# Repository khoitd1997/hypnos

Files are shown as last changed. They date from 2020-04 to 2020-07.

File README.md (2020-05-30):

# hypnos

Module embedded inside users' laptop to "remind" them to take break and sleep

## Background

I used to have a script that runs every couple hours to turn the computer off to remind me to take a break. However, that script can be easily bypassed and it's not cross-platform. Embedding `hypnos` into the motherboard of my laptop and enabling tamperproof protection in the BIOS for the case make it much harder to bypass.

## Features

- Interact with device through phone app
  - Allow users' actions to be asynchronous, save and transmit their actions when the device is connected
  - Allow a limited number of exceptions through tokens per month: Allow users to select a time range that they don't want to be disturbed, the number of tokens needed are automatically calculated and applied
    - Waving sleep time as well as applying many tokens in the same day should cost more to prevent binge
  - Customizable work and break duration(there has to be an upper and lower limit though)
  - Limit amount of total screen time per day
  - Statistics for tracking progress
  - Foreground task to show device status as well as current phase
  - Synchronize with app to keep correct time, remind users to connect to device if they haven't for a long time
  - Indicate the current time stretch
  - Bed time and wake time
  - Battery indicator
- Flexibly adapt to user' start of day
- Hard to abuse or bypass but also possible to remove when truly necessary
- Low power consumption
- User has pending actions like changing rest interval
- Need corrective actions such as clock syncing
- Reset switch for resetting all settings(including BLE bonding information)
- Small size: About 1.5 x 1.5 inch

## Custom GATT

The custom service is called the `Timetable Service`. `Base and other UUIDs` are taken [here](https://github.com/NordicPlayground/nRF5x-custom-ble-service-tutorial):

```c
// base is f364adc9-b000-4042-ba50-05ca45bf8abc
#define UUID_SERVICE 0x1400
```

To store an hour:minute info, needs 11 bits(5 for hour, 6(least significant) for minute) for 24-hour format. All timing is stored that way except for the current time service.

All times are in GMT.

All would require authentication to read/write

| UUID | Type | Data Type | Range |
| --- | --- | --- | --- |
| 0x1401 | MORNING_CURFEW_END | time type | 24-hour format |
| 0x1402 | NIGHT_CURFEW_START | time type | 24-hour format |
| 0x1403 | WORK_DURATION_MINUTE  | uint8 | 30-120 |
| 0x1404 | BREAK_DURATION_MINUTE | uint8 | 5-15 |
| 0x1405 | ACTIVE_EXCEPTIONS | list of pair unix time | 0-4 exceptions |
| 0x1406 | TOKENS_LEFT | uint8 | depend on policy implementation |
| 0x1407 | CURRENT_UNIX_TIME | uint32 | until saturation |

Max of 4 exceptions can be active at one time

## References

[BLE Chips Power Consumption](https://www.argenox.com/library/bluetooth-low-energy/bluetooth-le-chipset-guide-2019/#ble-device-comparison)
[Picking Advertising Interval](https://www.beaconzone.co.uk/ibeaconadvertisinginterval)

[Current Time Service](https://stackoverflow.com/questions/35695711/how-to-correctly-set-the-date-and-time-in-a-bluetooth-low-energy-peripheral)

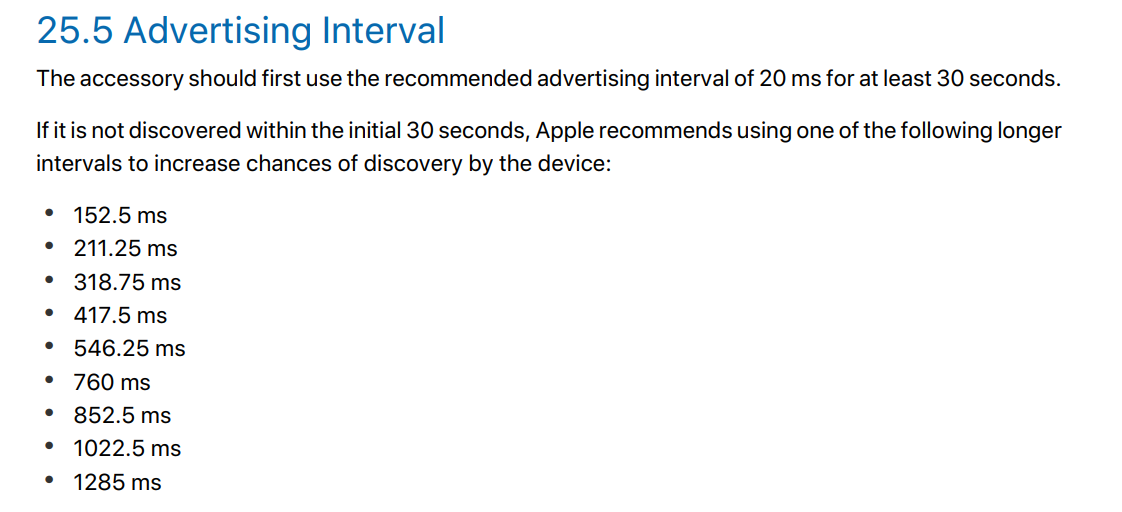
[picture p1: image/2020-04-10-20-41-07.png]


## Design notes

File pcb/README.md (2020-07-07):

# PCB

## Constraints

Use the area of the spare network card. That area has nice cable management path from the side that has the off switch.

- Max Length: 32 mm inside flat area, 8 mm outside at the first 11 mm in width (not overlapping a lot of PCB just wires)
- Max Width: 30 mm inside flat area, 20 mm overlapping with MB PCB (Need 9.5 mm for BT840F)
- Max Height: 5 mm

[NRF52 Max Voltage for GPIO][1]

The antenna inside the T480s should be 50 ohm.

## BT840F PCB Layout Notes

2-sided PCB is sufficient.

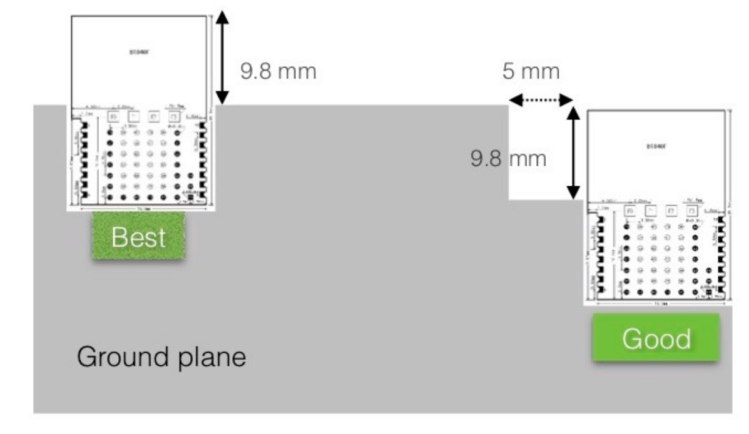
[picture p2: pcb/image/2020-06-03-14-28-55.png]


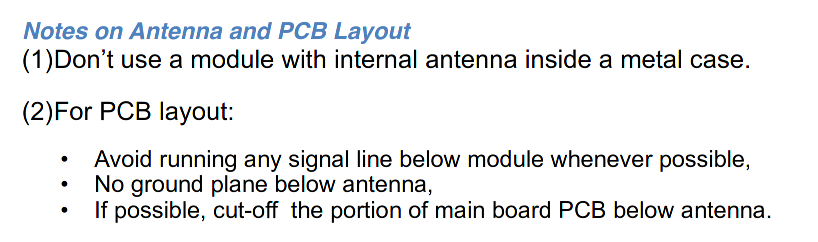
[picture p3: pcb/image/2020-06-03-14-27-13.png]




## Notes

The bare right angle pin has height 2.5 mm

[1]: https://infocenter.nordicsemi.com/index.jsp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

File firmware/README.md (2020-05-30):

# Hypnos Firmware

## Dependencies

Make sure `nRF Command Line Tools`, `JLink Driver` and `nrfutil`(pip) are installed

## How to build the firmware

The project uses `CMake` as the build system. But first, you need to generate cmake files for the nrf52 sdk since they originally supported only makefiles, then you can build various targets that do things from building the firmware to flashing the board.

```shell
# assuming working directory is the project root

# generate cmake files for sdk
# shouldn't needed to be run too often
# there will be some warnings but that's okay
./generate_cmake_file_for_sdk.sh

mkdir -p build
cd build
rm -rf ./* # if previous build was for the tests, reset the state

cmake .. -DCMAKE_TOOLCHAIN_FILE=../nrf_sdk/toolchain.cmake
cmake --build . --target flash_pca10056 # build and flash pca10056 firmware
```

A faster way than using the commandline cmake is to use the vscode CMake extension, the project already contains a file describing the cmake `nrf52 kit` to be used for building, so select that kit during configuration and you should be good.

## How to build the tests

The project uses `doctest` as its unit test framework to test files that are not hardware-depdendent. The test cases themselves are included in the source files of the code being tested themselves. To build:

```shell
# assuming working directory is the project root

mkdir -p build
cd build
rm -rf ./* # if previous build was for the firmware, reset the state

cmake ..
cmake --build . # build and run all tests by default
```

## Power Consumption Data

NRF52840 power consumption data, measured using a trueRMS multimeter with supply voltage of 3V, assuming bonded device. At the longest adv interval, the device is still detected and connected pretty fast, although to the time connect is inconsistent.

| Type | Adv Interval(0.625 ms) | uA  |
| ---- | --- | --- |
| Slow | 50 | 250 |
| Slow | 1000 | 70  |
| Slow | 3000 | 50  |
| Slow | 10000 | 40  |

## State Machine

### Top Level

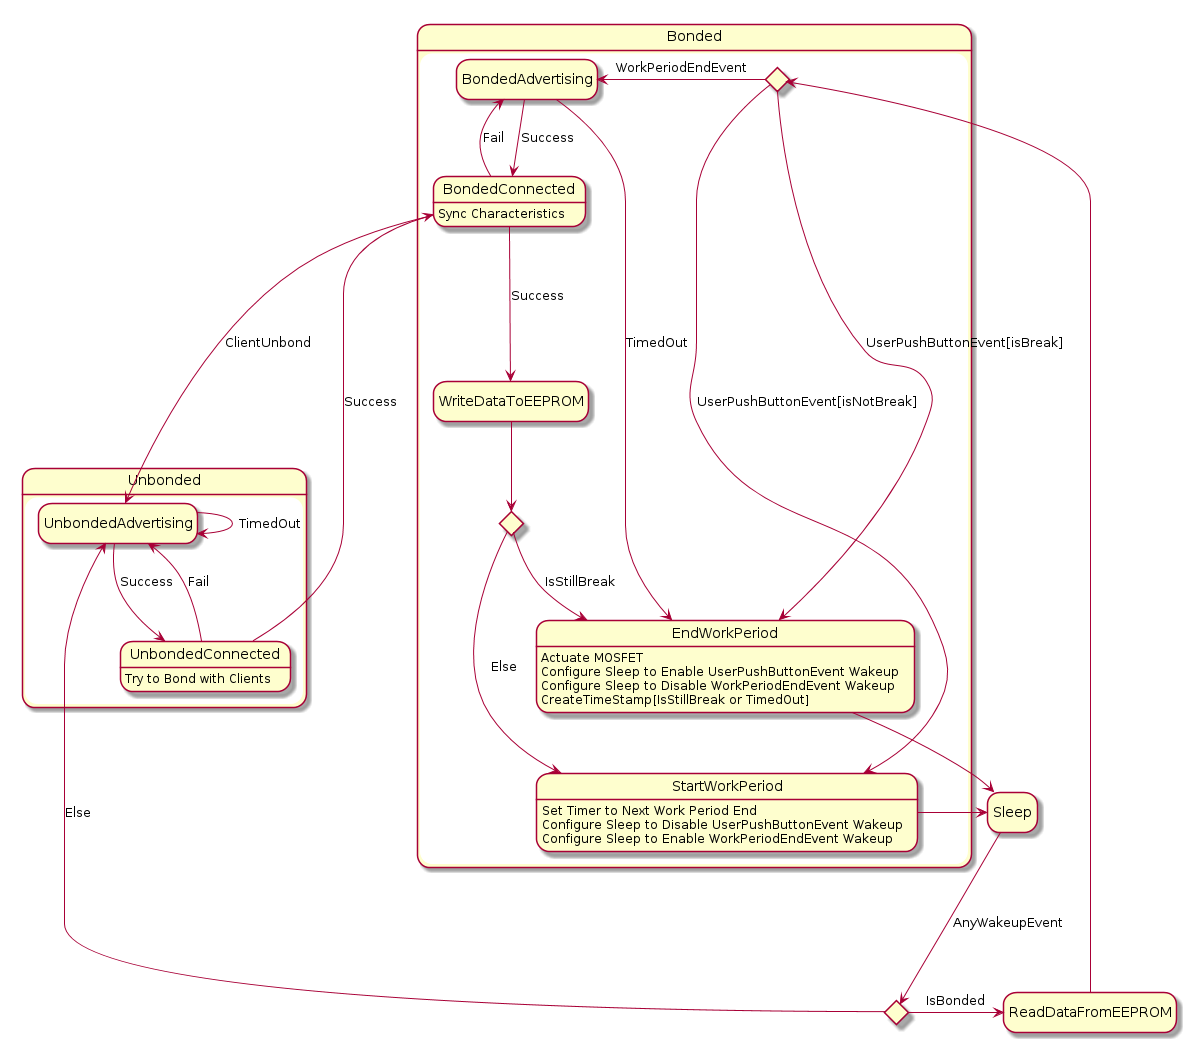
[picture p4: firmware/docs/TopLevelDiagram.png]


## References

The special event like BSP_EVENT_SYSOFF is assigned using:

```c
bsp_event_to_button_action_assign(BTN_ID_SLEEP,
                                  BSP_BUTTON_ACTION_LONG_PUSH,
                                  BSP_EVENT_SYSOFF);
```

[BSP Indication](https://infocenter.nordicsemi.com/index.jsp?topic=%2Fcom.nordic.infocenter.sdk5.v15.0.0%2Fgroup__bsp.html)
[BLE Security](https://duo.com/decipher/understanding-bluetooth-security)

[DCDC vs LDO power converter](https://devzone.nordicsemi.com/f/nordic-q-a/8106/internal-dcdc-vs-ldo-for-nrf52-series)

[Sending array in BLE data](https://devzone.nordicsemi.com/f/nordic-q-a/18040/ways-of-sending-a-float-array-as-a-value-of-a-characteristic)

[Software RTC](https://github.com/NordicPlayground/nrf5-calendar-example)
[Directed Advertising](https://devzone.nordicsemi.com/f/nordic-q-a/39950/directed-advertising---how-to-make-it-work)
[Power Optimization](https://www.argenox.com/library/bluetooth-low-energy/ble-advertising-primer/)
[CR2032 and NRF52](https://devzone.nordicsemi.com/f/nordic-q-a/36982/cr2032-coin-cell-battery-life-estimation-with-nrf52-as-beacon)

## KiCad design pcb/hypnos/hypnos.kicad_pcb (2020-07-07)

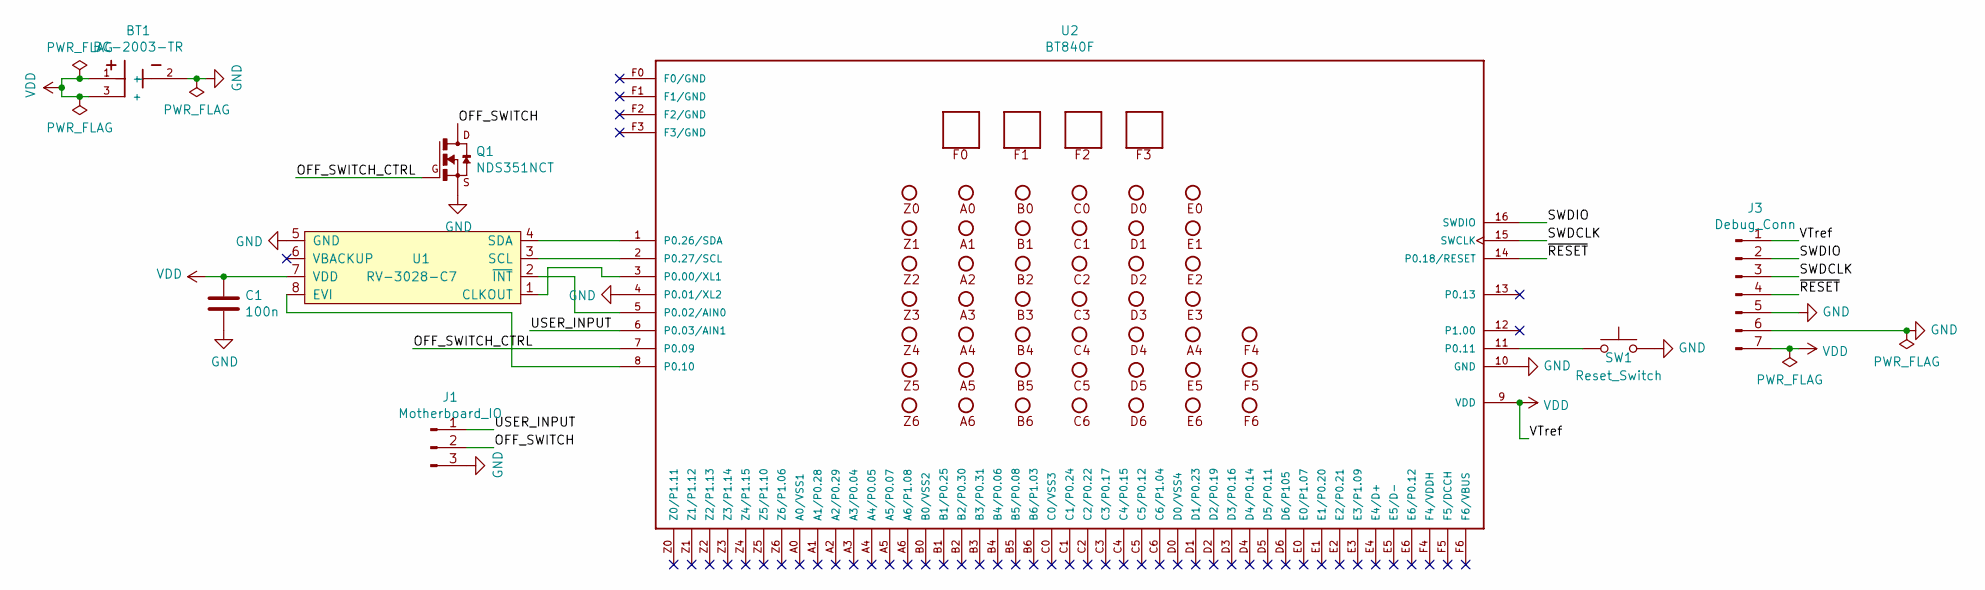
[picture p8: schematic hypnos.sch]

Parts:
BT1: BC-2003-TR
C1: 100n; C_0805_2012Metric_Pad1.15x1.40mm_HandSolder
J1: Motherboard_IO; Conn-Female-RightAnglex3-SMD
J3: Debug_Conn; Conn-Female-RightAnglex7-SMD
Q1: NDS351NCT; SOT-323_SC-70_Handsoldering
SW1: Reset_Switch; SW_KSR223GLFG
U1: RV-3028-C7
U2: BT840F

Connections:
/OFF_SWITCH: J1.2, Q1.3 (D)
/OFF_SWITCH_CTRL: Q1.1 (G), U2.7 (P0.09)
/SWDCLK: J3.3, U2.15 (SWCLK)
/SWDIO: J3.2, U2.16 (SWDIO)
/USER_INPUT: J1.1, U2.6 (P0.03/AIN1)
/~RESET: J3.4, U2.14 (P0.18/RESET)
GND: BT1.2 (-), C1.2, J1.3, J3.5, J3.6, Q1.2 (S), SW1.2, U1.5 (GND), U2.4 (P0.01/XL2), U2.10 (GND)
unnamed: SW1.1, U2.11 (P0.11)
unnamed: U1.1 (CLKOUT), U2.3 (P0.00/XL1)
unnamed: U1.2 (~INT), U2.5 (P0.02/AIN0)
unnamed: U1.3 (SCL), U2.2 (P0.27/SCL)
unnamed: U1.4 (SDA), U2.1 (P0.26/SDA)
unnamed: U1.8 (EVI), U2.8 (P0.10)
VDD: BT1.1 (+), BT1.3 (+), C1.1, J3.1, J3.7, U1.7 (VDD), U2.9 (VDD)

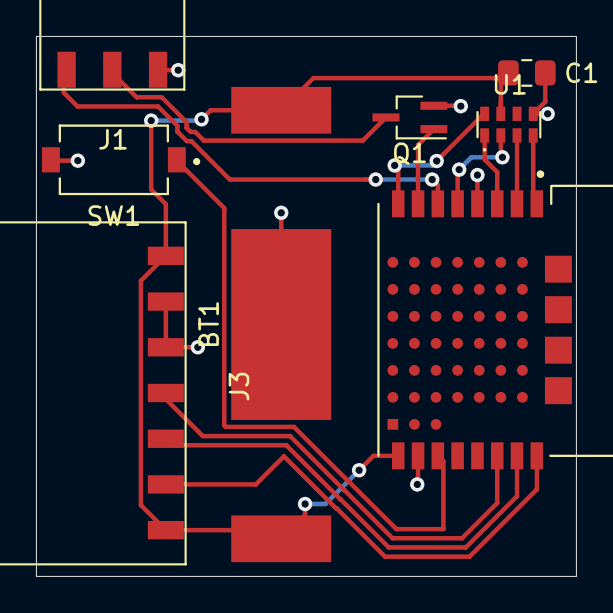
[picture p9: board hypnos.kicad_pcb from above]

Board: 2 copper layers, 30.0 x 30.0 mm, 8 parts (0 on the bottom side), 14 nets.

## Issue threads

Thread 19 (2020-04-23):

PCB Parts

khoitd1997, 2020-04-23:

khoitd1997, 2020-04-23:
[Dongle Material Files](https://www.nordicsemi.com/Software-and-tools/Development-Kits/nRF52840-Dongle/Download#infotabs)

khoitd1997, 2020-05-10:
Need to have a reset switch to clear things like bonding details

khoitd1997, 2020-06-09:
Input High Voltage for nrf52832 is 0.7xVdd. For 3V Vdd, that will be 2.1V.

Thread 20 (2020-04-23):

RV-3028 Driver

khoitd1997, 2020-04-23:
This chip was selected since it has a dev board and really low current consumption. [Linux kernel driver](https://github.com/torvalds/linux/blob/master/drivers/rtc/rtc-rv3028.c)

Features to Implement:

- User EEPROM access
- Interrupt based on timer count down to wake up MCU, make sure to select the correct timer clock frequency, also wake up based on time of day for curfews
- Set alarm for certain time of day
- Read/Write current time in UNIX
- Output waveform to serve as LFO for nrf52

Closed 2020-05-11.

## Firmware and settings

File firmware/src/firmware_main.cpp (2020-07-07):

/**
 * Copyright (c) 2016 - 2019, Nordic Semiconductor ASA
 *
 * All rights reserved.
 *
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
 * 3. Neither the name of Nordic Semiconductor ASA nor the names of its
 *    contributors may be used to endorse or promote products derived from this
 *    software without specific prior written permission.
 *
 * 4. This software, with or without modification, must only be used with a
 *    Nordic Semiconductor ASA integrated circuit.
 *
 * 5. Any software provided in binary form under this license must not be reverse
 *    engineered, decompiled, modified and/or disassembled.
 *
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
 */

#include <stdint.h>

#include "app_error.h"
#include "ble.h"

#include "ble_hci.h"
#include "fds.h"
#include "nordic_common.h"
#include "nrf.h"

#include "nrf_pwr_mgmt.h"
#include "nrf_sdh.h"
#include "nrf_sdh_ble.h"
#include "nrf_sdh_soc.h"

#include "nrf_nvic.h"

#include "nrf_log.h"
#include "nrf_log_ctrl.h"

#include "nrf_delay.h"

#include "ble_module.hpp"

#include "advertising_module.hpp"

#include "connection_module.hpp"

#include "gatt_module.hpp"

#include "gap_module.hpp"

#include "peer_manager_handler.h"
#include "pm_module.hpp"

#include "bms_module.hpp"
#include "qwr_module.hpp"

#include "bas_module.hpp"

#include "timetable_service_module.hpp"

#include "adc_module.hpp"

#include "power_module.hpp"

#include "computer_switch_module.hpp"

#include "rv3028.hpp"
#include "twi_module.hpp"

#include "state_machine.hpp"

#include "misc_module.hpp"
#include "nrf_log_default_backends.h"

/**@brief Callback function for asserts in the SoftDevice.
 *
 * @details This function will be called in case of an assert in the SoftDevice.
 *
 * @warning This handler is an example only and does not fit a final product. You need to analyze
 *          how your product is supposed to react in case of Assert.
 * @warning On assert from the SoftDevice, the system can only recover on reset.
 *
 * @param[in]   line_num   Line number of the failing ASSERT call.
 * @param[in]   file_name  File name of the failing ASSERT call.
 */
void assert_nrf_callback(uint16_t line_num, const uint8_t* p_file_name) {
  NRF_LOG_FINAL_FLUSH();
  //!< Value used as error code on stack dump, can be used to identify stack location on
  //!< stack unwind.
  app_error_handler(0xDEADBEEF, line_num, p_file_name);
}

// TODO(khoi): Remove this after development is done
#pragma GCC diagnostic ignored "-Wunused-function"

// void testFunc() { SEGGER_SYSVIEW_RecordU32(0 + testModule.EventOffset, 5); }

constexpr nrfx_gpiote_pin_t COMPUTER_SWITCH_PIN     = NRF_GPIO_PIN_MAP(0, 9);
constexpr nrfx_gpiote_pin_t USER_INPUT_PIN          = NRF_GPIO_PIN_MAP(0, 3);
constexpr nrfx_gpiote_pin_t RTC_INTERRUPT_INPUT_PIN = NRF_GPIO_PIN_MAP(0, 2);
constexpr nrfx_gpiote_pin_t RTC_TIME_STAMP_PIN      = NRF_GPIO_PIN_MAP(0, 10);
constexpr nrfx_gpiote_pin_t RESET_PIN               = NRF_GPIO_PIN_MAP(0, 11);

void configure_reset_pin() {
  nrf_drv_gpiote_in_config_t in_config = GPIOTE_CONFIG_IN_SENSE_HITOLO(false);
  in_config.pull                       = NRF_GPIO_PIN_NOPULL;

  const auto err_code = nrf_drv_gpiote_in_init(
      RESET_PIN, &in_config, [](nrf_drv_gpiote_pin_t pin, nrf_gpiote_polarity_t action) {
        nrf_drv_gpiote_in_event_disable(RESET_PIN);
        ble::pm::delete_all_bonds_unsafe();
        sd_nvic_SystemReset();
      });
  APP_ERROR_CHECK(err_code);

  nrf_drv_gpiote_in_event_enable(RESET_PIN, true);
}

// APP_TIMER_DEF(m_timer_id);

int main(void) {
  {
    const auto err_code = NRF_LOG_INIT(NULL);
    APP_ERROR_CHECK(err_code);

    NRF_LOG_DEFAULT_BACKENDS_INIT();
  }
  auto err_code = nrf_pwr_mgmt_init();
  APP_ERROR_CHECK(err_code);
  {
    const auto err_code = nrf_drv_gpiote_init();
    APP_ERROR_CHECK(err_code);
  }

  configure_reset_pin();

  // need to initialize but not call nrf_drv_gpiote_in_event_enable otherwise
  // latch clear doesn't seem to work
  {
    nrf_drv_gpiote_in_config_t in_config = GPIOTE_CONFIG_IN_SENSE_HITOLO(false);
    in_config.pull                       = NRF_GPIO_PIN_NOPULL;
    const auto err_code = nrf_drv_gpiote_in_init(RTC_INTERRUPT_INPUT_PIN, &in_config, nullptr);
    APP_ERROR_CHECK(err_code);
    nrf_drv_gpiote_in_event_disable(RTC_INTERRUPT_INPUT_PIN);
  }
  {
    nrf_drv_gpiote_in_config_t in_config = GPIOTE_CONFIG_IN_SENSE_HITOLO(false);
    in_config.pull                       = NRF_GPIO_PIN_NOPULL;
    const auto err_code = nrf_drv_gpiote_in_init(USER_INPUT_PIN, &in_config, nullptr);
    APP_ERROR_CHECK(err_code);
    nrf_drv_gpiote_in_event_disable(USER_INPUT_PIN);
  }

  NRF_LOG_INFO("User input pin state: %d", nrf_gpio_pin_read(USER_INPUT_PIN));
  NRF_LOG_INFO("RTC input pin state: %d", nrf_gpio_pin_read(RTC_INTERRUPT_INPUT_PIN));
  NRF_LOG_INFO("Reset input pin state: %d", nrf_gpio_pin_read(RESET_PIN));

  if (nrf_gpio_pin_latch_get(USER_INPUT_PIN)) { NRF_LOG_INFO("user input latch set"); }
  if (nrf_gpio_pin_latch_get(RTC_INTERRUPT_INPUT_PIN)) { NRF_LOG_INFO("rtc interrupt latch set"); }
  if (nrf_gpio_pin_latch_get(RESET_PIN)) { NRF_LOG_INFO("reset latch set"); }
  NRF_LOG_INFO("Latch is %x", NRF_GPIO->LATCH);

  nrf_delay_ms(500);
  NRF_GPIO->LATCH = NRF_GPIO->LATCH;
  (void)NRF_TIMER1->EVENTS_COMPARE[0];

  // give the latch some time to clear
  NRF_LOG_INFO("Yo");
  NRF_LOG_INFO("Yo");
  NRF_LOG_INFO("Yo");
  NRF_LOG_INFO("Yo");
  NRF_LOG_FLUSH();

  while (nrf_gpio_pin_latch_get(USER_INPUT_PIN) ||
         nrf_gpio_pin_latch_get(RTC_INTERRUPT_INPUT_PIN) || nrf_gpio_pin_latch_get(RESET_PIN)) {
    // make sure the latch is cleared
  }

  NRF_LOG_INFO("Preparing to Sleep, latch: %d", NRF_GPIO->LATCH);
  NRF_LOG_FLUSH();

  nrf_drv_gpiote_in_event_enable(RTC_INTERRUPT_INPUT_PIN, true);
  nrf_drv_gpiote_in_event_enable(USER_INPUT_PIN, true);

  {
    auto err_code = nrf_sdh_enable_request();
    APP_ERROR_CHECK(err_code);

    // Fetch the start address of the application RAM.
    uint32_t ram_start;
    err_code = nrf_sdh_ble_default_cfg_set(1, &ram_start);
    APP_ERROR_CHECK(err_code);

    err_code = nrf_sdh_ble_enable(&ram_start);
    APP_ERROR_CHECK(err_code);

    NRF_SDH_BLE_OBSERVER(m_ble_observer, 3, nullptr, NULL);

    ble_opt_t opt;

    memset(&opt, 0x00, sizeof(opt));
    opt.common_opt.conn_evt_ext.enable = 1;

    err_code = sd_ble_opt_set(BLE_COMMON_OPT_CONN_EVT_EXT, &opt);
    APP_ERROR_CHECK(err_code);
  }

  sd_power_system_off();
  while (1) {
    // in debug mode, sleep is emulated
  }
}

/**
 * @}
 */

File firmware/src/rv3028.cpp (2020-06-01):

/******************************************************************************
Constantin Koch
July 25, 2019
https://github.com/constiko/RV-3028_C7-Arduino_Library

Development environment specifics:
Arduino IDE 1.8.9

This code is released under the [MIT License](http://opensource.org/licenses/MIT).
Please review the LICENSE.md file included with this example. If you have any questions
or concerns with licensing, please contact constantinkoch@outlook.com.
Distributed as-is; no warranty is given.
******************************************************************************/

#include "rv3028.hpp"

#include <cstdio>
#include <ctime>

#include "app_error.h"
#include "nrf_log.h"
#include "nrf_log_ctrl.h"

#include "nrf_delay.h"

#include "misc_module.hpp"
#include "twi_module.hpp"

//****************************************************************************//
//
//  Settings and configuration
//
//****************************************************************************//

// Parse the __DATE__ predefined macro to generate date defaults:
// __Date__ Format: MMM DD YYYY (First D may be a space if <10)
// <MONTH>
#define BUILD_MONTH_JAN ((__DATE__[0] == 'J') && (__DATE__[1] == 'a')) ? 1 : 0
#define BUILD_MONTH_FEB (__DATE__[0] == 'F') ? 2 : 0
#define BUILD_MONTH_MAR \
  ((__DATE__[0] == 'M') && (__DATE__[1] == 'a') && (__DATE__[2] == 'r')) ? 3 : 0
#define BUILD_MONTH_APR ((__DATE__[0] == 'A') && (__DATE__[1] == 'p')) ? 4 : 0
#define BUILD_MONTH_MAY \
  ((__DATE__[0] == 'M') && (__DATE__[1] == 'a') && (__DATE__[2] == 'y')) ? 5 : 0
#define BUILD_MONTH_JUN \
  ((__DATE__[0] == 'J') && (__DATE__[1] == 'u') && (__DATE__[2] == 'n')) ? 6 : 0
#define BUILD_MONTH_JUL \
  ((__DATE__[0] == 'J') && (__DATE__[1] == 'u') && (__DATE__[2] == 'l')) ? 7 : 0
#define BUILD_MONTH_AUG ((__DATE__[0] == 'A') && (__DATE__[1] == 'u')) ? 8 : 0
#define BUILD_MONTH_SEP (__DATE__[0] == 'S') ? 9 : 0
#define BUILD_MONTH_OCT (__DATE__[0] == 'O') ? 10 : 0
#define BUILD_MONTH_NOV (__DATE__[0] == 'N') ? 11 : 0
#define BUILD_MONTH_DEC (__DATE__[0] == 'D') ? 12 : 0
#define BUILD_MONTH                                                                             \
  BUILD_MONTH_JAN | BUILD_MONTH_FEB | BUILD_MONTH_MAR | BUILD_MONTH_APR | BUILD_MONTH_MAY |     \
      BUILD_MONTH_JUN | BUILD_MONTH_JUL | BUILD_MONTH_AUG | BUILD_MONTH_SEP | BUILD_MONTH_OCT | \
      BUILD_MONTH_NOV | BUILD_MONTH_DEC
// <DATE>
#define BUILD_DATE_0 ((__DATE__[4] == ' ') ? 0 : (__DATE__[4] - 0x30))
#define BUILD_DATE_1 (__DATE__[5] - 0x30)
#define BUILD_DATE ((BUILD_DATE_0 * 10) + BUILD_DATE_1)
// <YEAR>
#define BUILD_YEAR                                                                              \
  (((__DATE__[7] - 0x30) * 1000) + ((__DATE__[8] - 0x30) * 100) + ((__DATE__[9] - 0x30) * 10) + \
   ((__DATE__[10] - 0x30) * 1))

// Parse the __TIME__ predefined macro to generate time defaults:
// __TIME__ Format: HH:MM:SS (First number of each is padded by 0 if <10)
// <HOUR>
#define BUILD_HOUR_0 ((__TIME__[0] == ' ') ? 0 : (__TIME__[0] - 0x30))
#define BUILD_HOUR_1 (__TIME__[1] - 0x30)
#define BUILD_HOUR ((BUILD_HOUR_0 * 10) + BUILD_HOUR_1)
// <MINUTE>
#define BUILD_MINUTE_0 ((__TIME__[3] == ' ') ? 0 : (__TIME__[3] - 0x30))
#define BUILD_MINUTE_1 (__TIME__[4] - 0x30)
#define BUILD_MINUTE ((BUILD_MINUTE_0 * 10) + BUILD_MINUTE_1)
// <SECOND>
#define BUILD_SECOND_0 ((__TIME__[6] == ' ') ? 0 : (__TIME__[6] - 0x30))
#define BUILD_SECOND_1 (__TIME__[7] - 0x30)
#define BUILD_SECOND ((BUILD_SECOND_0 * 10) + BUILD_SECOND_1)

RV3028& RV3028::get() {
  static RV3028 singleton;
  return singleton;
}

bool RV3028::init(nrfx_gpiote_pin_t time_stamp_pin,
                  bool              set_24Hour,
                  bool              disable_TrickleCharge,
                  bool              set_LevelSwitchingMode) {
  if (set_24Hour) { set24Hour(); }
  if (disable_TrickleCharge) { disableTrickleCharge(); }

  _time_stamp_pin                        = time_stamp_pin;
  nrf_drv_gpiote_out_config_t out_config = GPIOTE_CONFIG_OUT_SIMPLE(false);
  const auto                  err_code   = nrf_drv_gpiote_out_init(_time_stamp_pin, &out_config);
  APP_ERROR_CHECK(err_code);
  nrf_drv_gpiote_out_clear(_time_stamp_pin);

  return set_LevelSwitchingMode ? setBackupSwitchoverMode(3) : true;
}

bool RV3028::setTime(uint8_t    sec,
                     uint8_t    min,
                     uint8_t    hour,
                     uint8_t    weekday,
                     uint8_t    date,
                     uint8_t    month,
                     uint16_t   year,
                     const bool syncUnix) {
  _time[TIME_SECONDS] = DECtoBCD(sec);
  _time[TIME_MINUTES] = DECtoBCD(min);
  _time[TIME_HOURS]   = DECtoBCD(hour);
  _time[TIME_WEEKDAY] = DECtoBCD(weekday);
  _time[TIME_DATE]    = DECtoBCD(date);
  _time[TIME_MONTH]   = DECtoBCD(month);
  _time[TIME_YEAR]    = DECtoBCD(year - 2000);

  if (syncUnix) {
    tm tmVar{
        .tm_sec   = sec,
        .tm_min   = min,
        .tm_hour  = hour,
        .tm_mday  = date,
        .tm_mon   = month - 1,
        .tm_year  = year - 1900,
        .tm_wday  = weekday,
        .tm_isdst = 1,
    };
    const auto unixTime = static_cast<uint32_t>(mktime(&tmVar));
    setUNIX(unixTime, false);
  }

  bool status = false;

  if (is12Hour()) {
    set24Hour();
    status = setTime(_time, TIME_ARRAY_LENGTH);
    set12Hour();
  } else {
    status = setTime(_time, TIME_ARRAY_LENGTH);
  }
  return status;
}

// setTime -- Set time and date/day registers of RV3028 (using data array)
bool RV3028::setTime(uint8_t* time, uint8_t len) {
  if (len != TIME_ARRAY_LENGTH) return false;

  return writeMultipleRegisters(RV3028_SECONDS, time, len);
}

bool RV3028::setSeconds(uint8_t value) {
  _time[TIME_SECONDS] = DECtoBCD(value);
  return setTime(_time, TIME_ARRAY_LENGTH);
}

bool RV3028::setMinutes(uint8_t value) {
  _time[TIME_MINUTES] = DECtoBCD(value);
  return setTime(_time, TIME_ARRAY_LENGTH);
}

bool RV3028::setHours(uint8_t value) {
  _time[TIME_HOURS] = DECtoBCD(value);
  return setTime(_time, TIME_ARRAY_LENGTH);
}

bool RV3028::setWeekday(uint8_t value) {
  _time[TIME_WEEKDAY] = DECtoBCD(value);
  return setTime(_time, TIME_ARRAY_LENGTH);
}

bool RV3028::setDate(uint8_t value) {
  _time[TIME_DATE] = DECtoBCD(value);
  return setTime(_time, TIME_ARRAY_LENGTH);
}

bool RV3028::setMonth(uint8_t value) {
  _time[TIME_MONTH] = DECtoBCD(value);
  return setTime(_time, TIME_ARRAY_LENGTH);
}

bool RV3028::setYear(uint16_t value) {
  _time[TIME_YEAR] = DECtoBCD(value - 2000);
  return setTime(_time, TIME_ARRAY_LENGTH);
}

// Takes the time from the last build and uses it as the current time
// Works very well as an arduino sketch
bool RV3028::setToCompilerTime() { return setUNIX(CURR_UNIX_TIME); }
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

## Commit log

2020-04-11 added oscilloscope current measurement guide
2020-04-17 Initial BLE firmware and App (#11)
    [app_bar_main.xml]
2020-04-22 Battery service (#16)
2020-05-11 Rv3028 and GPIO driver (#28)
2020-05-11 Current unix time characteristic (#29)
2020-05-31 added computer switch module (#35)
2020-06-01 added initial pcb
    [hypnos.kicad_pcb, hypnos.sch]
2020-06-03 finished schematics, ready for pcb
    [hypnos.kicad_pcb]
2020-06-07 changed pin assignments
2020-07-07 backup work
    [hypnos-B_Cu.gbr, hypnos-B_Mask.gbr, hypnos-B_Paste.gbr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]
